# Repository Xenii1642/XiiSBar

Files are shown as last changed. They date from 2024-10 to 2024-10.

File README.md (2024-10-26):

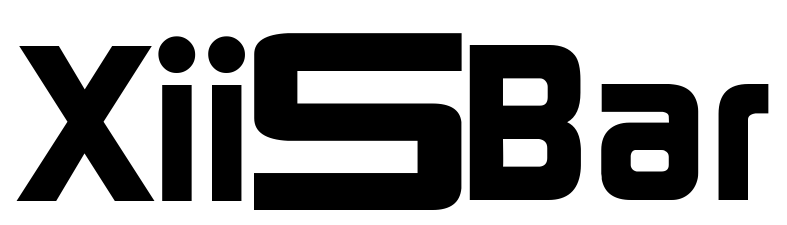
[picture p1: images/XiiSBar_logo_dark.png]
<picture> <source media="(prefers-color-scheme: dark)" srcset="images/XiiSBar_logo.png">  </picture> 

The XiiSBar is a small portable Sensor Bar. It is useful to fully use the WiiMote on your portable Wii. 

Its small form factor means that you can put it under a Xii-Boy Pocket stand !

Check this Bitbuilt Thread for further informations: [XiiSBar's Bitbuilt Thread](https://bitbuilt.net/forums/index.php?threads/the-xiisbar.6623/)

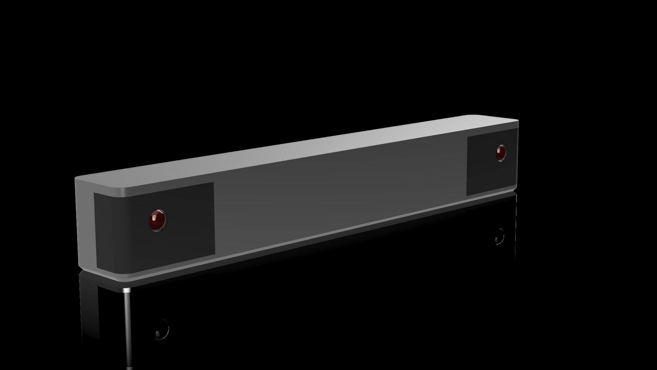
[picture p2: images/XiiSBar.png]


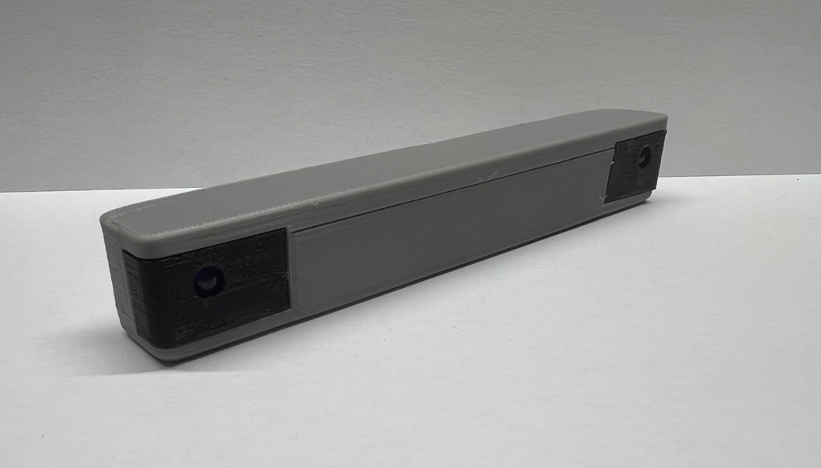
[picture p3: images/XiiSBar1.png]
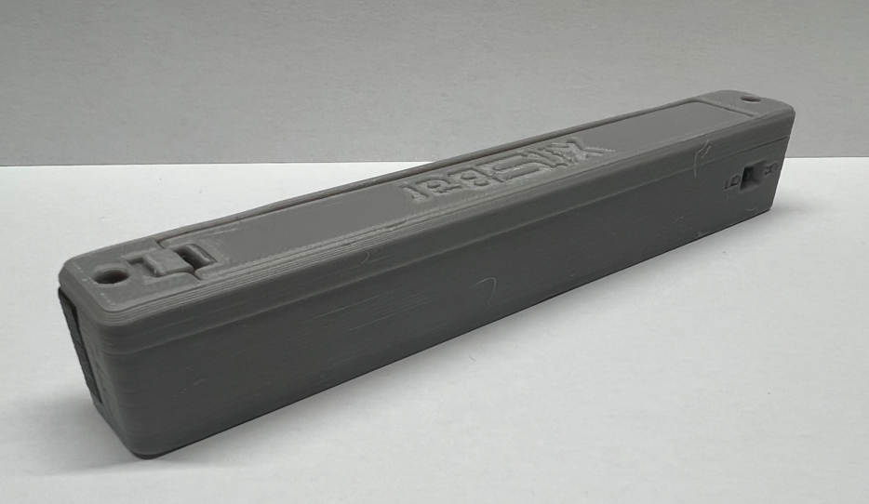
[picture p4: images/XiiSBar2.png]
 
## PCB
First, you'll need to order the XiiSBar PCB through [JLCPCB](https://jlcpcb.com/), [PCBWay](https://www.pcbway.com/), [Next PCB](https://www.nextpcb.com/) or  the manufacturer you prefer. 
I personally order mine through [JLCPCB](https://jlcpcb.com/) because it's the cheapest. 

Generally, PCBWay offers a better PCB quality. However, the XiiSBar PCB is very simple, and doesn't require the best quality.
#
Once you've chosen you're manufacturer, upload the [XiiSBar PCB Geber file](https://github.com/Xenii1642/XiiSBar/tree/main/PCB%20Files/Gerber). 

Let the settings by default. Only change the color if you want. Once your order is done, you'll have to order the components for the PCB.

All the components are listed in the [BOM file](https://github.com/Xenii1642/XiiSBar/blob/main/BOM.pdf). I personally ordered them through [Digikey](https://www.digikey.com/en/products).
#
Once you have the PCB and the components, you'll have to assemble it. Each component on the [BOM file](https://github.com/Xenii1642/XiiSBar/blob/main/BOM.pdf) correspond to each label on the PCB.
I used a solder iron set to 360℃ (680℉) with Lead-Free solder. Once the assembly is done, your PCB should look like this:

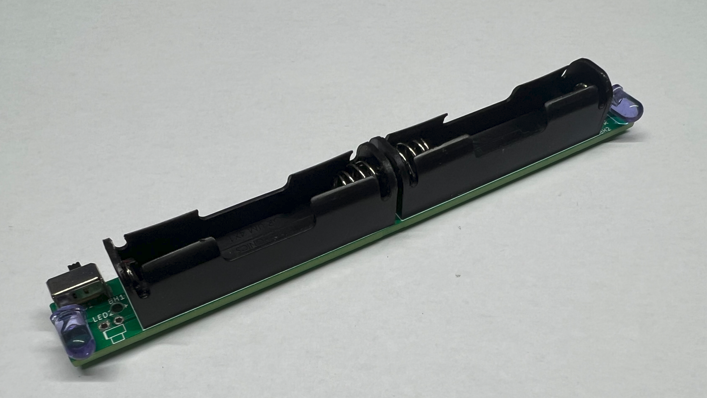
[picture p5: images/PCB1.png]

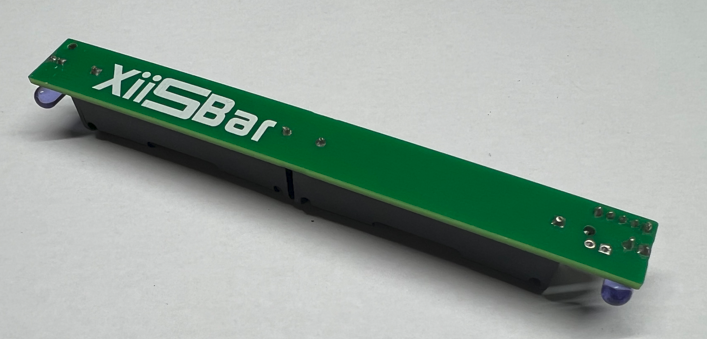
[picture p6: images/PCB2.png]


## Assembly
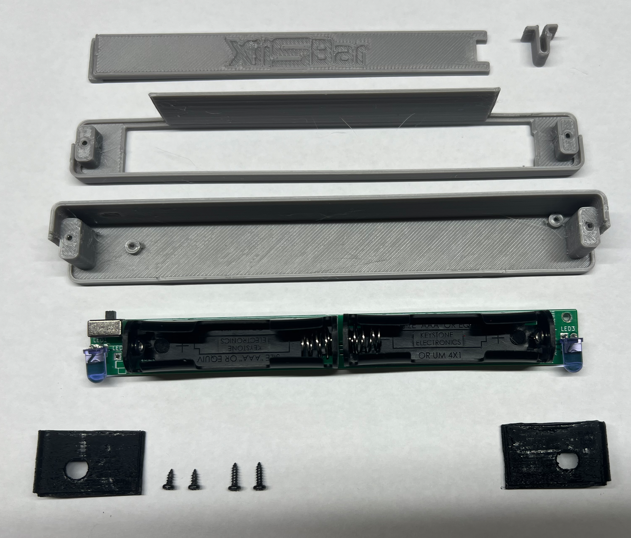
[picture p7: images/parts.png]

This is all the parts you need to build a XiiSBar. 
All the STLs for the 3D printed parts are in the STL folder 😉

#
First, put the switch slider in the switch hole of the case. Then, rotate the board in place.

⚠ This last part could be a bit tricky considering the small tolerances ⚠

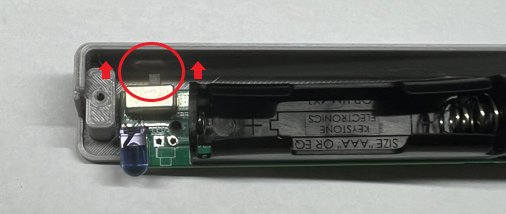
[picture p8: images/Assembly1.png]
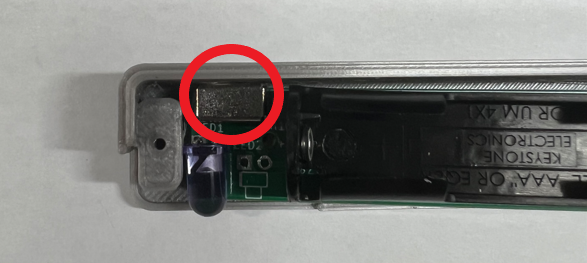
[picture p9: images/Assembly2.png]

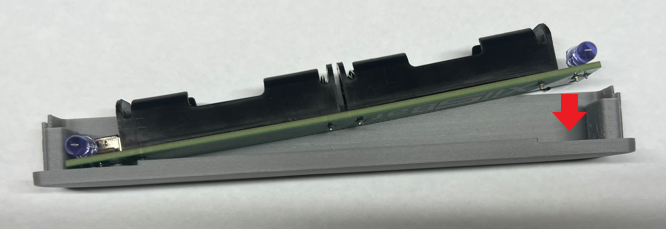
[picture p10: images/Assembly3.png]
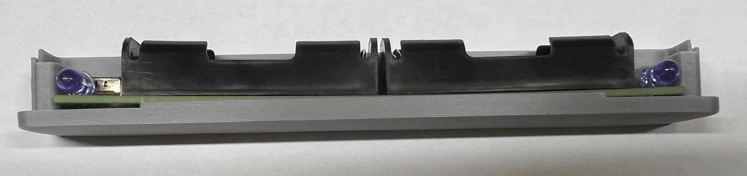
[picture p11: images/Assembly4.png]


After that, you'll need to screew the board in place. Use the M1.7x4 ones.

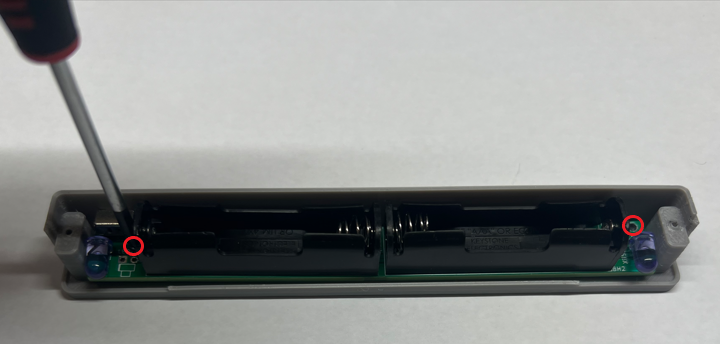
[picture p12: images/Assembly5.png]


Place this piece as shown below and then fold it. Do the same thing for the other black piece.

⚠ If you deceided to solder the optional LED2, you have to use the "Right + LED" piece instead. ⚠

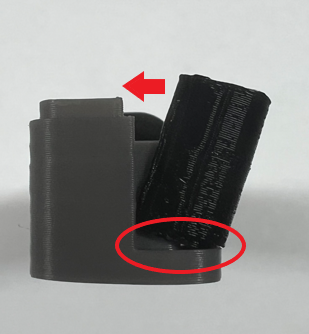
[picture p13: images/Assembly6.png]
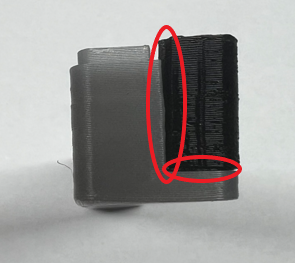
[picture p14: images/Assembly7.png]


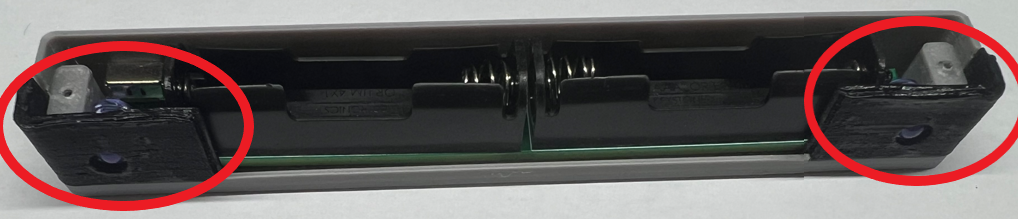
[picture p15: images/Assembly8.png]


Now, take this piece and place it like this. You should be able to close the case.

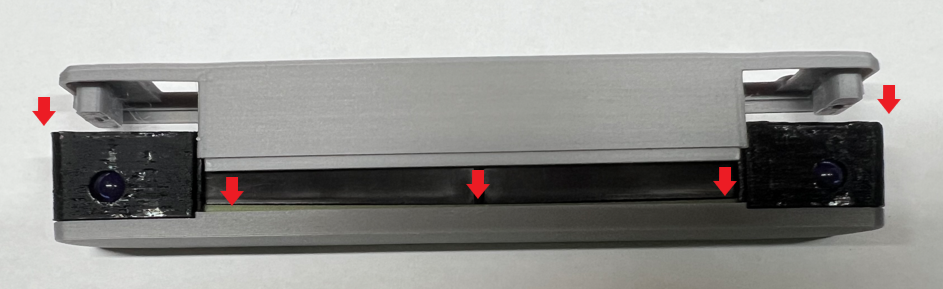
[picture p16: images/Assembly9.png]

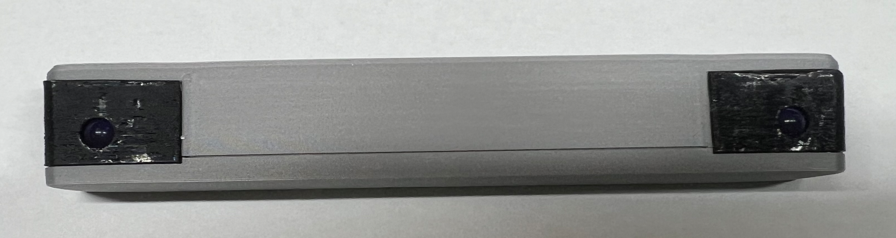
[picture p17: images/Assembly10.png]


Take two M1.7x6 screws and screw the case.

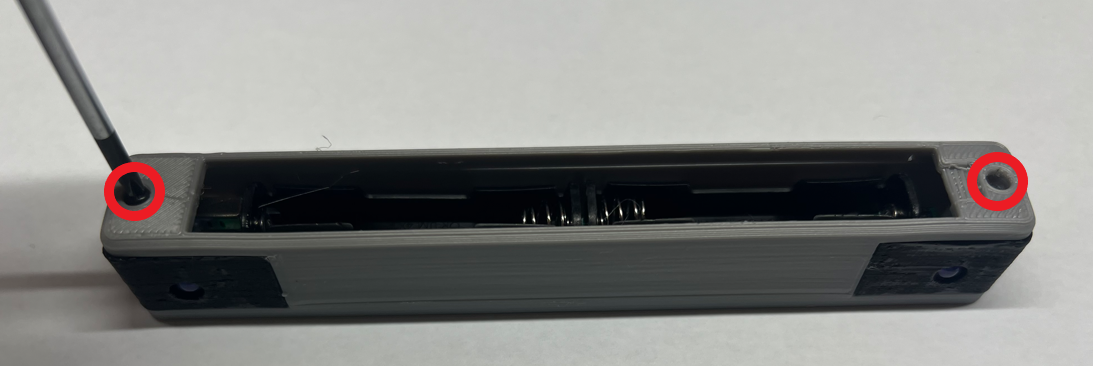
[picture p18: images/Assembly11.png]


Finally, take the battery cover and the clip. Put both parts together.⚠ You might need some super glue ⚠

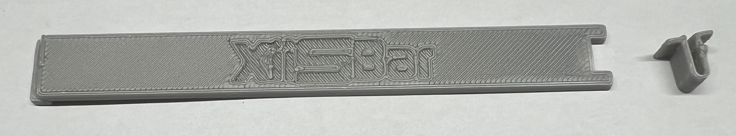
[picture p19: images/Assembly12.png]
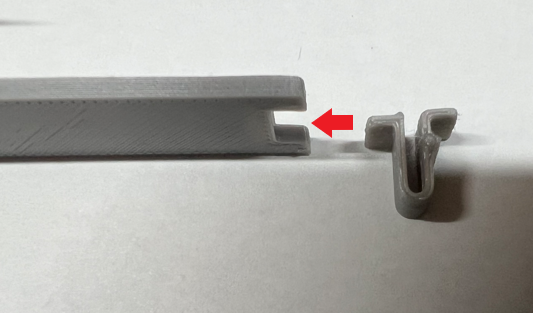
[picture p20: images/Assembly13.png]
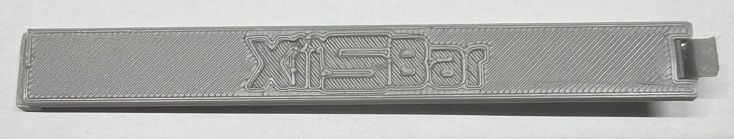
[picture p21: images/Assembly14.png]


Finally, put the battery cover on the case and close it ! That's it !

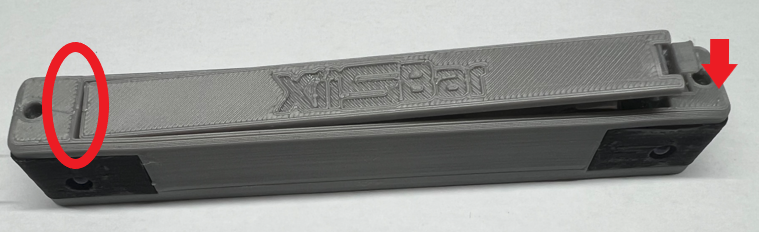
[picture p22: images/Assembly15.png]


If you have any question during the assembly, about the files or other, don't hesistate to ask me 👍

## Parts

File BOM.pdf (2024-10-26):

XiiSBar BOM

XiiSBar PCB
Reference | Quantity | Descrition | Manufacter Product Number | Link
BH1, BH2 | | 2 Battery Holder AAA PC PIN | 2466 | https://www.digikey.com/en/products/detail/keystone-electronics/2466/303815
LED1, LED3 | | 2 IR LED DIODE CW-PULSD 3.3MW/CM2 | VTE1291-1H | https://www.digikey.com/en/products/detail/excelitas-technologies/VTE1291-1H/5885863
LED2 (Optional) | | 1 LED RED CLEAR T/H | SLR-342VCTB7 | https://www.digikey.com/en/products/detail/w%C3%BCrth-elektronik/151031SS04000/4489979
S1 | | 1 8.6 X 4.5 X 8.7 MM, 2 MM RAISED | SLW-864587-2A-RA-N-D | https://www.digikey.com/en/products/detail/cui-devices/SLW-864587-2A-RA-N-D/24399384

Other
Screws M1.7x4 | | 2 100PCS‎M1.7*4‎5‎6‎8‎10‎Small… | None | https://www.aliexpress.com/item/1005002027885700.html
Screws M1.7x6 | | 2 100PCS‎M1.7*4‎5‎6‎8‎10‎Small… | None | https://www.aliexpress.com/item/1005002027885700.html

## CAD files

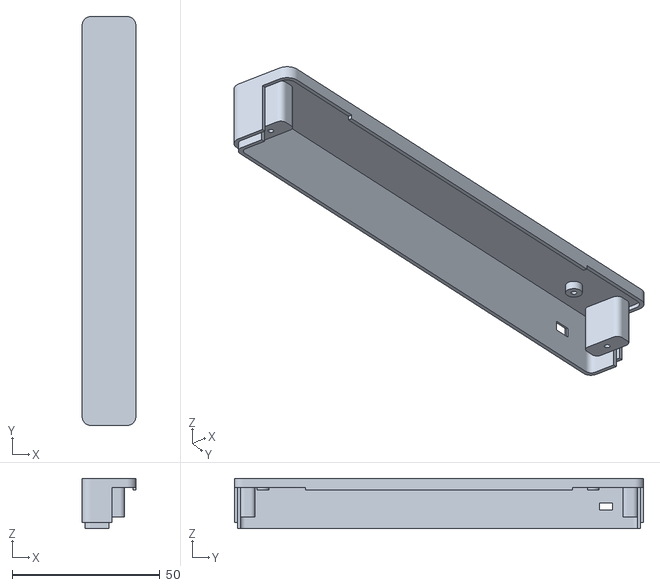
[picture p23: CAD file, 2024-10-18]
STL/Top.stl
18.2 x 138.5 x 17.0

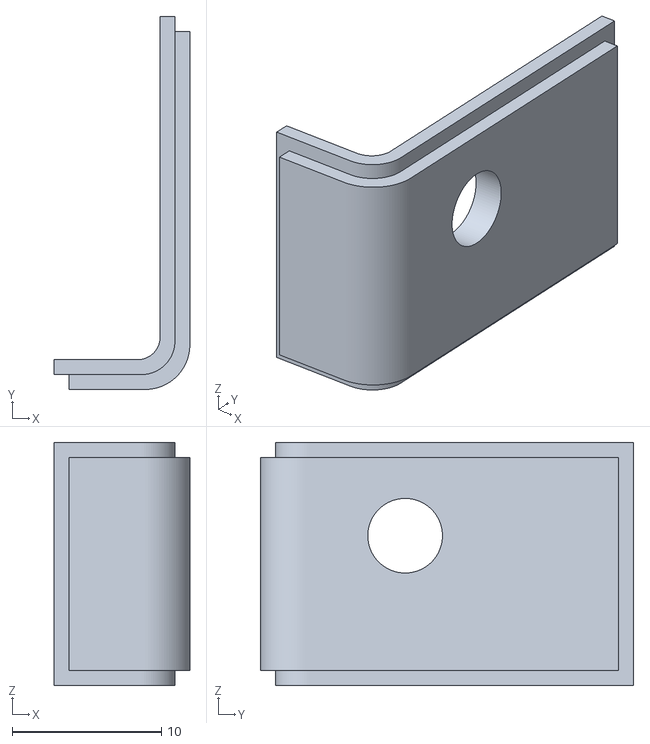
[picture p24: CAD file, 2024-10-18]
STL/Left.stl
9.10 x 25.0 x 16.3

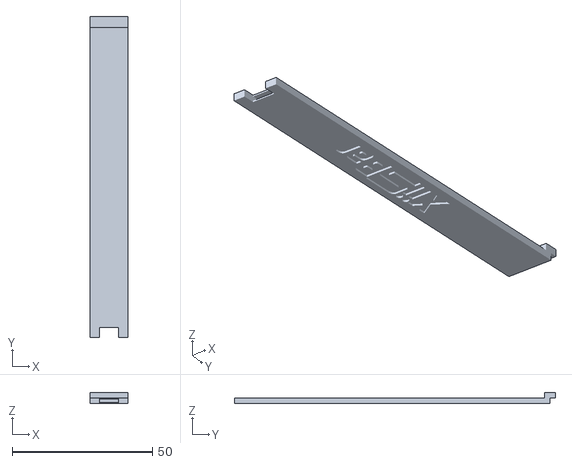
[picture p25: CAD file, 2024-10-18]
STL/Battery Cover.stl
13.5 x 114.5 x 4.00

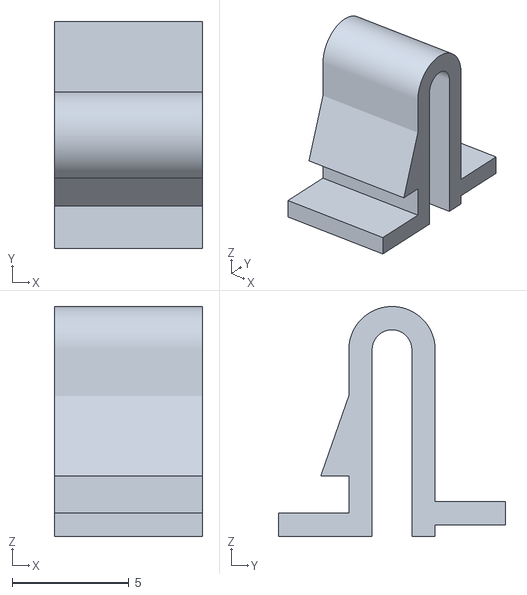
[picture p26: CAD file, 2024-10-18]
STL/Clip.stl
6.35 x 9.70 x 9.85

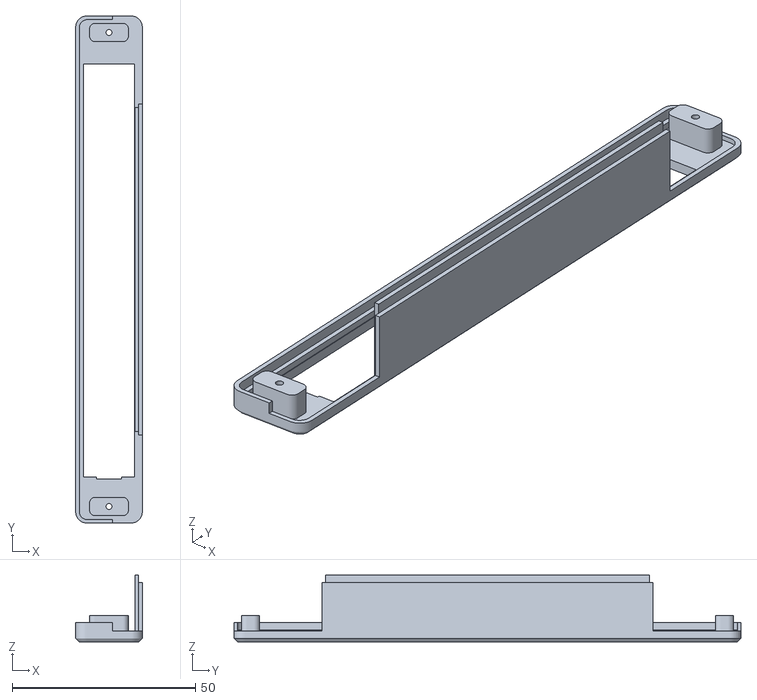
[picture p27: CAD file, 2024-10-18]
STL/Bottom.stl
18.2 x 138.5 x 18.3

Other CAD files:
STL/Right + LED.stl
STL/Right.stl

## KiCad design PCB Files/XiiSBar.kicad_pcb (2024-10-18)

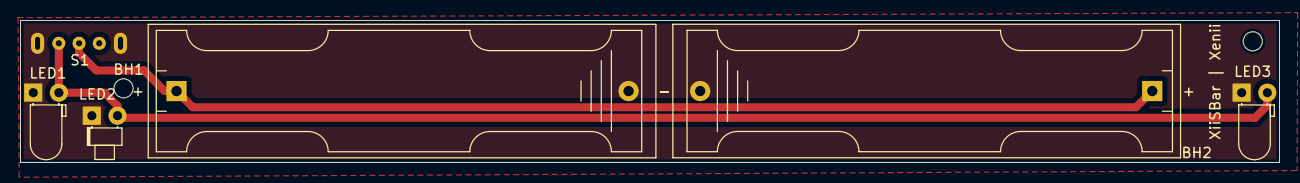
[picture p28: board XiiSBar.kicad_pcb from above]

Board: 2 copper layers, 124.5 x 14.0 mm, 6 parts (0 on the bottom side), 3 nets.

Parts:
BT1, BT2: Battery_Cell; BatteryHolder_Keystone_2466_1xAAA
D1, D2: LED; LED_D3.0mm_Horizontal_O1.27mm_Z10.0mm
D3: LED; LED_D1.8mm_W1.8mm_H2.4mm_Horizontal_O1.27mm_Z1.6mm
U1: SLW-864587-2A-RA-N-D

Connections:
GND: BT1.2 (-), BT2.2 (-), D1.1 (K), D2.1 (K), D3.1 (K), U1.4, U1.5
unnamed: BT1.1 (+), BT2.1 (+), U1.2
unnamed: D1.2 (A), D2.2 (A), D3.2 (A), U1.3
